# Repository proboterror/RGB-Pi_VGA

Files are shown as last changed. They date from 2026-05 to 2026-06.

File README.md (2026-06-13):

# RGB-Pi with VGA 15 kHz

Improved [RGB-Pi adapter](https://www.rgb-pi.com) for use with RGB-Pi OS.

Based on [open schematic published by mortaca](https://github.com/mortaca/RGB-Pi).

Original RGB-Pi documentation: [www.mortaca.com/docs/wiki](https://www.mortaca.com/docs/wiki/index.php?title=RGB-Pi)

Changes:
- Added VGA (DSUB-15) 15 kHz connector (Warning: 31 kHz VGA monitors not supported). 
- Proper sync combiner, borrowed from from [BKM-129X clone board](https://github.com/skumlos/bkm-129x-scart-vga), see also [KabukiFlux's RGBpi cable sync mixer](https://github.com/KabukiFlux/pi-rgb-cable-sync-mixer).
- Improved R-2R RGB DAC.
- PWM audio buffered with [SN74LVC2G34 Dual Buffer Gate](<datasheets/SN74LVC2G34 Dual Buffer Gate.pdf>) powered from [PS7A2033 Ultra-Low-Noise LDO](<datasheets/TPS7A20 300-mA, Ultra-Low-Noise, Low-IQ, High PSRR LDO.pdf>), with separate analog ground, in order to reduce Raspberry Pi internal power noise.
- Added 3.5 mm audio jack connector.

## Schematics:<br>
Scheme

## Board view:<br>
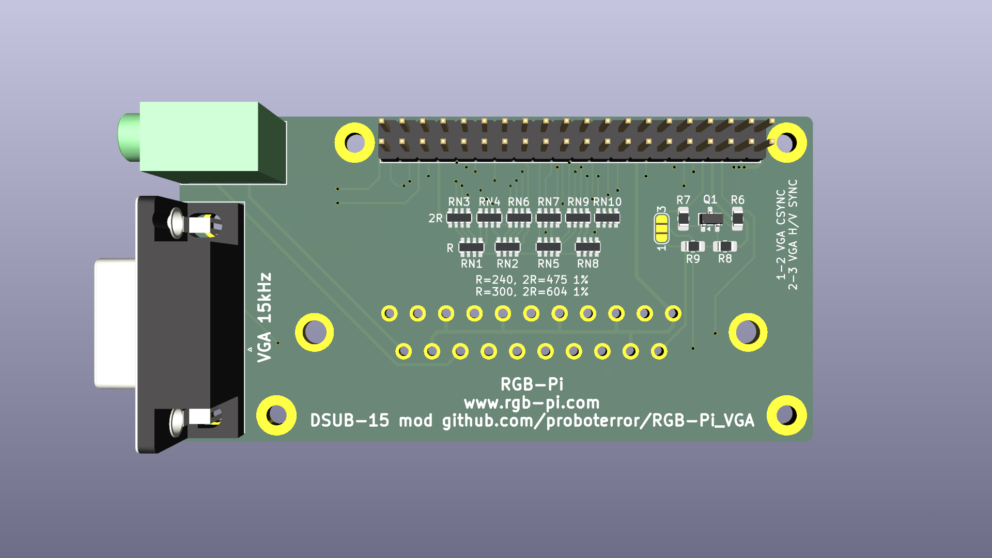
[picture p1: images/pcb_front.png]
Front

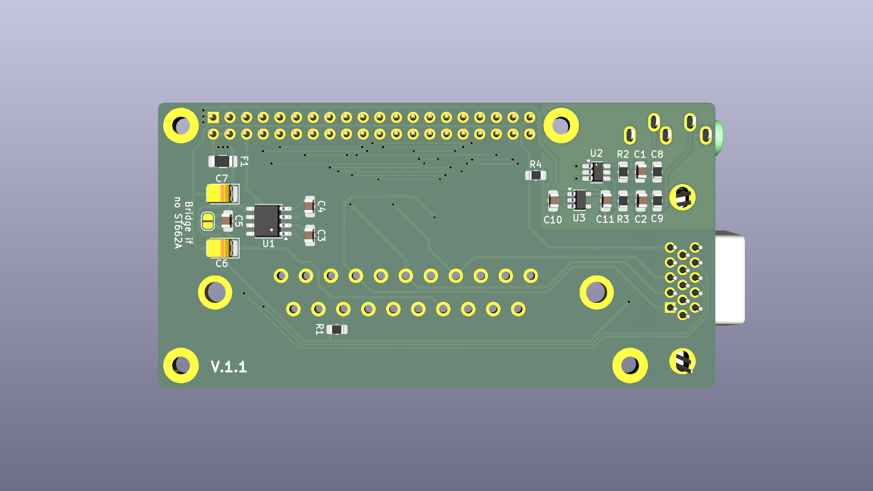
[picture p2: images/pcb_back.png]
Back

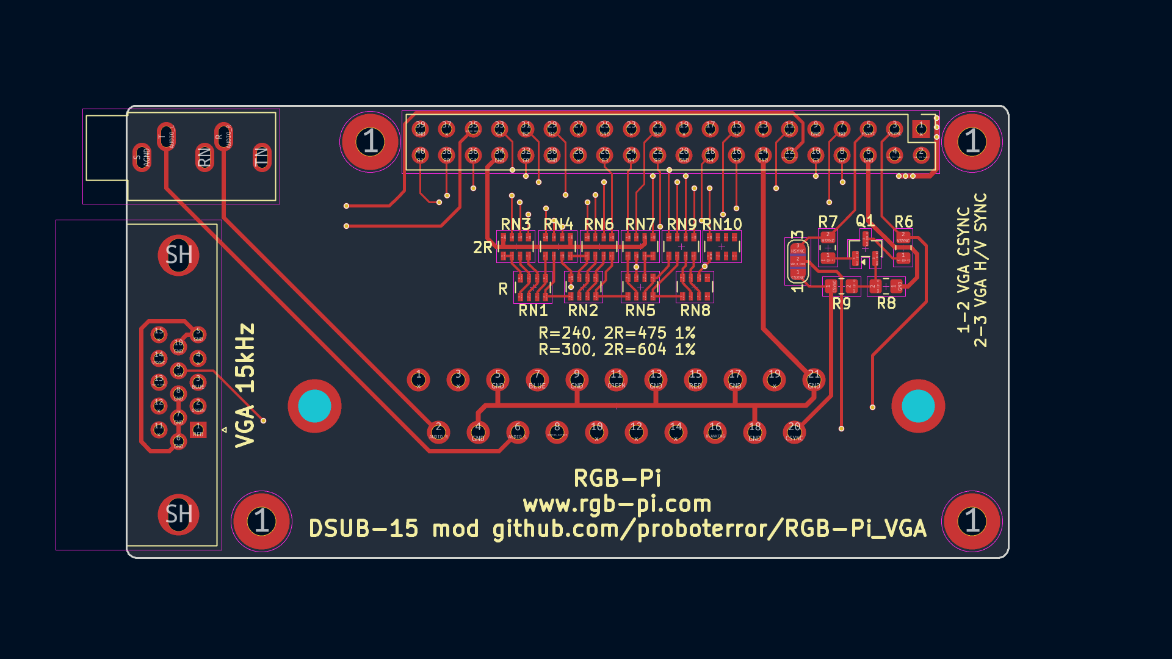
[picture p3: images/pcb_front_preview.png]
Front preview

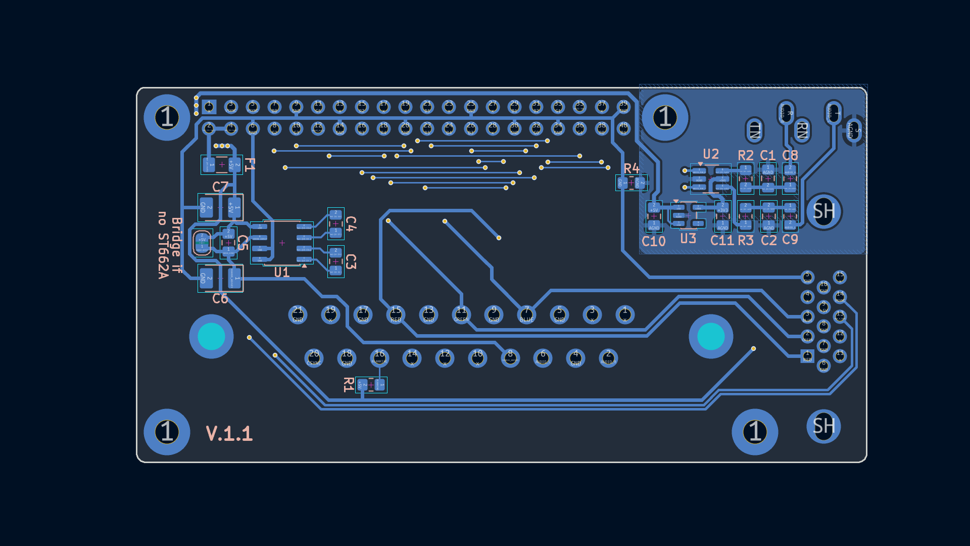
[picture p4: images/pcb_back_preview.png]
Back preview

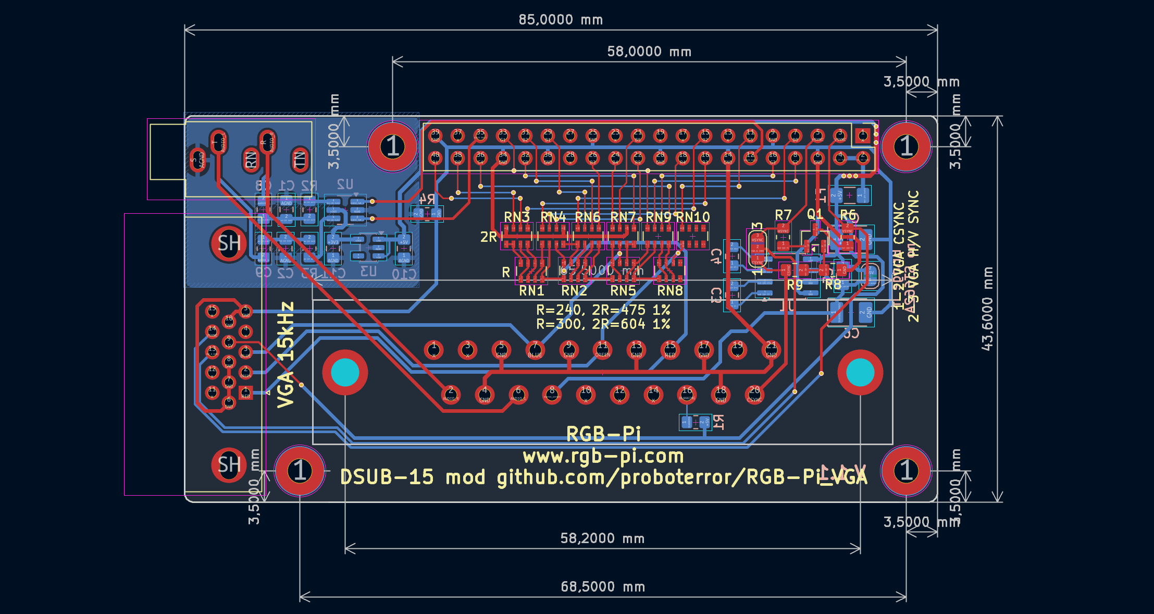
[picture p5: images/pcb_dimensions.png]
PCB dimensions


## Bill of Materials
|Reference|Value|Footprint|Qty|
|-----|-----|-----|-----|
|C1,C2|100nF|0805|2|
|C8,C9|10uF|0805|2|
|U2|SN74LVC2G34DBVR|SOT-23-6|1|
|U3|TPS7A2033PDBVR|SOT-23-5|1|
|F1|MF-NSMF012-2| 1206 Bourns MF-NSMF012-2 0.12A 30V|1|
|J1|Raspberry_Pi_4| PinHeader_2x20_P2.54mm_Vertical |1|
|J2|SCART-F|CS-102 (SCART-21S)|1|
|J3|DE15 Socket / DSUB-15-HD / VGA| DSUB-15-HD_Socket_Horizontal P2.29x1.90mm EdgePinOffset3.03mm MountingHolesOffset4.94mm|1|
|J4|SJ1-3535NG|CUI/Same Sky Device SJ1-3535NG|1|
|Q1|MMBT3904|SOT-23|1|
|R1|120R|0805|1|
|R2,R3|1K|0805|2|
|R6|100R|0805|1|
|R7|10K|0805|1|
|R8|1K|0805|1|
|R9|470R|0805|1|
|RN1,RN2,RN5,RN8|R = 240R or 300R 1%|Resistor Array 4x0603 |4|
|RN3,RN4,RN6,RN7,RN9,RN10|2R = 475R or 604R 1%|Resistor Array 4x0603|6|

Optional (SCART 5V->12V Converter for Status & Aspect Ratio switch):

|Reference|Value|Footprint|Qty|
|-----|-----|-----|-----|
|C5|100nF|0805|1|
|C3,C4|220nF|0805|2|
|C6,C7|4.7uF|Tantalum EIA-3528-21 / Kemet-B|2|
|U1|ST662A|SO-8_3.9x4.9mm_P1.27mm|1|

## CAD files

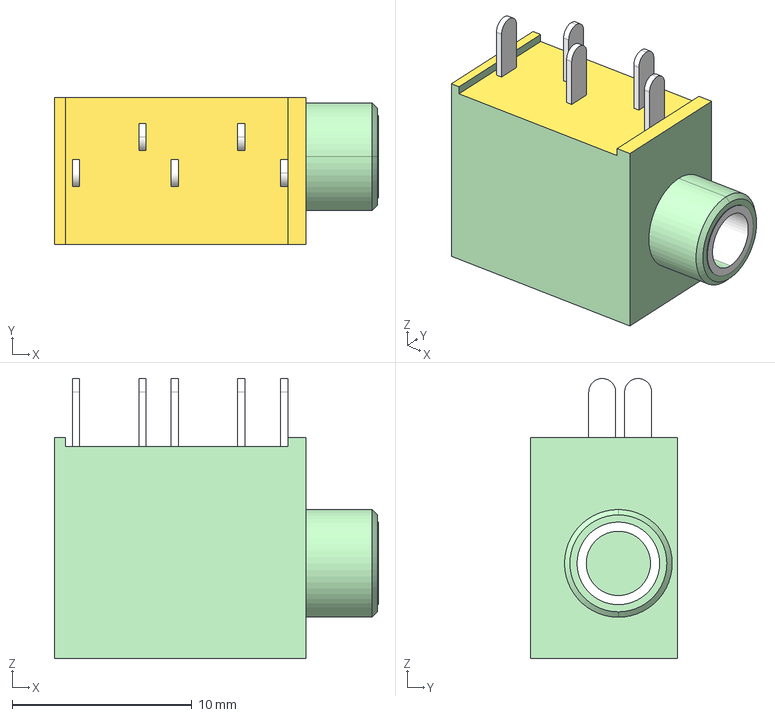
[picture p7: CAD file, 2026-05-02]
KiCad/3dshapes/CUI_DEVICES_SJ1-3535NG-G.step
18.1 x 8.20 x 15.6 mm

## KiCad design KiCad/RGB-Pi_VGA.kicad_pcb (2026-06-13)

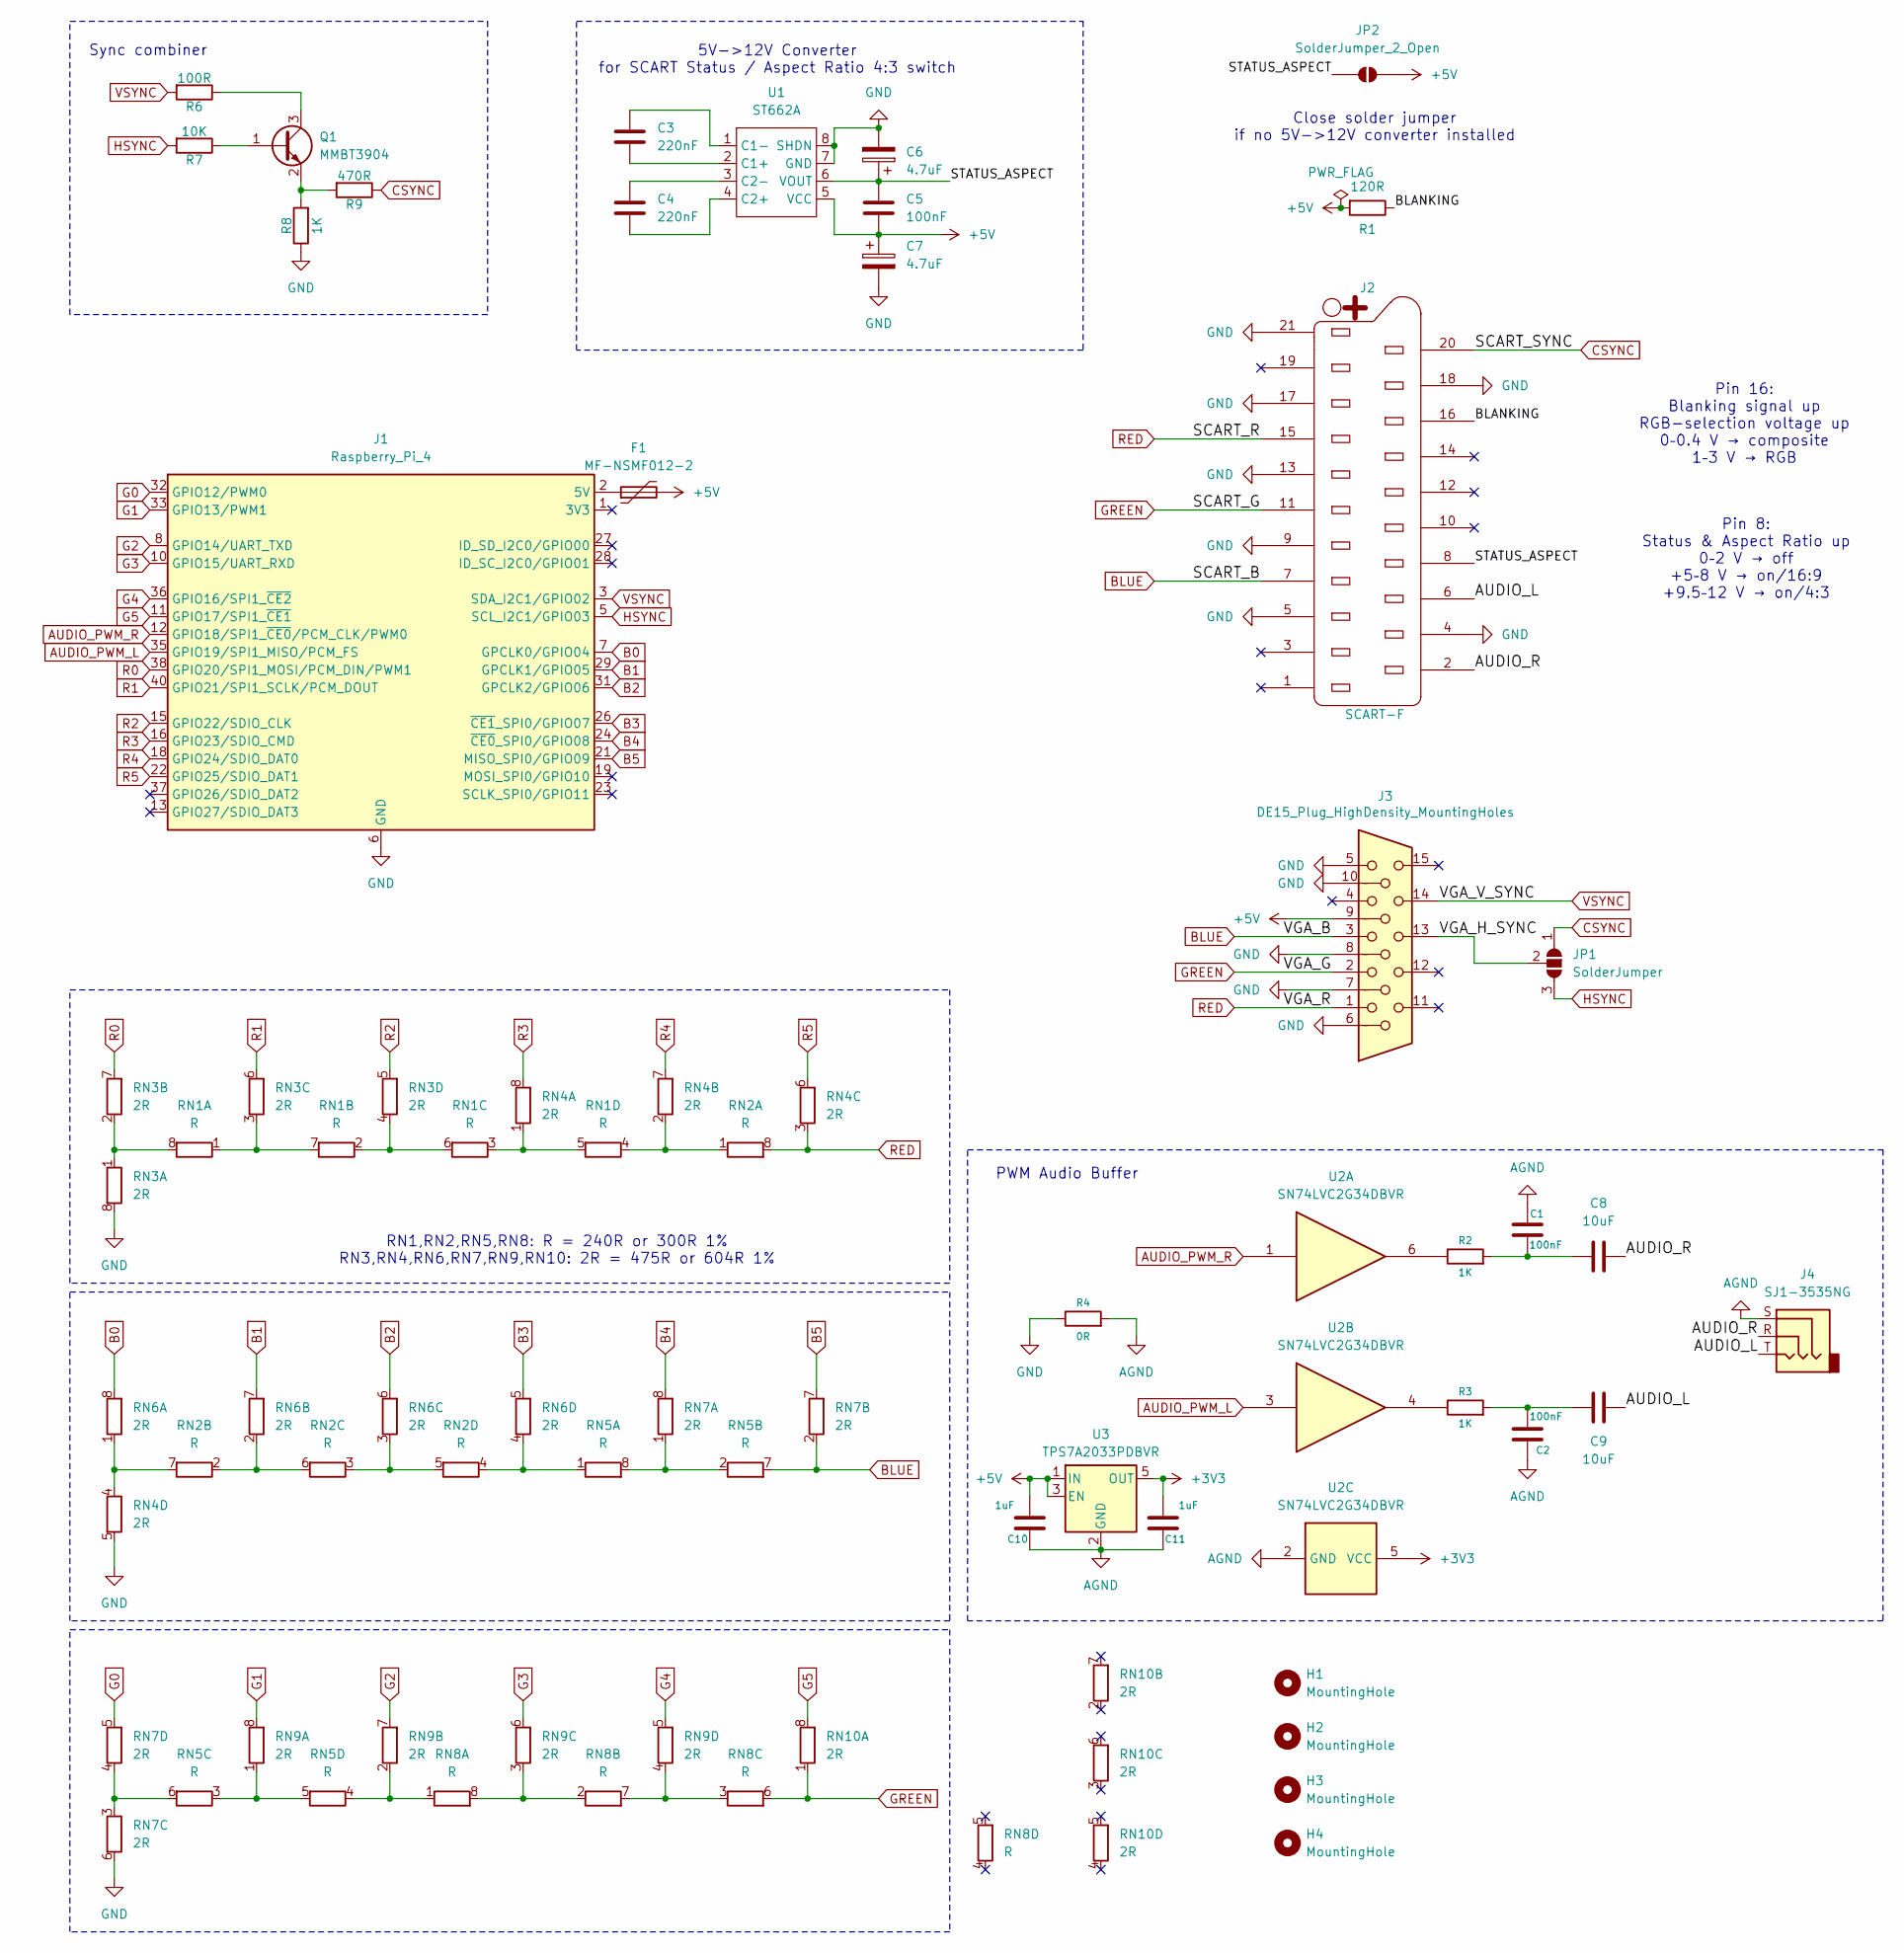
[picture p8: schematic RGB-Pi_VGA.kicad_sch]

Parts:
C1, C2, C5: 100nF; C_0805_2012Metric_Pad1.18x1.45mm_HandSolder
C3, C4: 220nF; C_0805_2012Metric_Pad1.18x1.45mm_HandSolder
C6, C7: 4.7uF; CP_EIA-3528-21_Kemet-B_HandSolder
C8, C9: 10uF; R_0805_2012Metric_Pad1.20x1.40mm_HandSolder
C10, C11: 1uF; C_0805_2012Metric_Pad1.18x1.45mm_HandSolder
F1: MF-NSMF012-2; Fuse_1206_3216Metric_Pad1.42x1.75mm_HandSolder
H1, H2, H3, H4: MountingHole; MountingHole_2.7mm_Pad
J1: Raspberry_Pi_4; PinHeader_2x20_P2.54mm_Vertical
J2: SCART-F; K-SCARTX-024
J3: DE15_Plug_HighDensity_MountingHoles; DSUB-15-HD_Socket_Horizontal_P2.29x1.90mm_EdgePinOffset3.03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
J4: SJ1-3535NG; Jack_3.5mm_CUI_SJ1-3535NG_Horizontal
JP1: SolderJumper; SolderJumper-3_P1.3mm_Open_RoundedPad1.0x1.5mm_NumberLabels
JP2: SolderJumper_2_Open; SolderJumper-2_P1.3mm_Open_RoundedPad1.0x1.5mm
Q1: MMBT3904; SOT-23
R1: 120R; R_0805_2012Metric_Pad1.20x1.40mm_HandSolder
R2, R3, R8: 1K; R_0805_2012Metric_Pad1.20x1.40mm_HandSolder
R4: 0R; R_0805_2012Metric_Pad1.20x1.40mm_HandSolder
R6: 100R; R_0805_2012Metric_Pad1.20x1.40mm_HandSolder
R7: 10K; R_0805_2012Metric_Pad1.20x1.40mm_HandSolder
R9: 470R; R_0805_2012Metric_Pad1.20x1.40mm_HandSolder
RN1, RN2, RN5, RN8: R; R_Array_Convex_4x0603
RN3, RN4, RN6, RN7, RN9, RN10: 2R; R_Array_Convex_4x0603
U1: ST662A; SO-8_3.9x4.9mm_P1.27mm
U2: SN74LVC2G34DBVR; SOT-23-6_Handsoldering
U3: TPS7A2033PDBVR; SOT-23-5

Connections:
+3V3: C11.2, U2.5 (VCC), U3.5 (OUT)
+5V: C5.2, C7.1, C10.2, F1.2, J3.9, JP2.2 (B), R1.2, U1.5 (VCC), U3.1 (IN), U3.3 (EN)
/AUDIO_L: C9.2, J2.6, J4.T
/AUDIO_R: C8.2, J2.2, J4.R
/BLANKING: J2.16, R1.1
/STATUS_ASPECT: C5.1, C6.1, J2.8, JP2.1 (A), U1.6 (VOUT)
/VGA_H_SYNC: J3.13, JP1.2 (C)
AGND: C1.1, C2.1, C10.1, C11.1, J4.S, R4.2, U2.2 (GND), U3.2 (GND)
AUDIO_PWM_L: J1.35 (GPIO19/SPI1_MISO/PCM_FS), U2.3
AUDIO_PWM_R: J1.12 (GPIO18/SPI1_~CE0/PCM_CLK/PWM0), U2.1
B0: J1.7 (GPCLK0/GPIO04), RN6.8 (R1.2)
B1: J1.29 (GPCLK1/GPIO05), RN6.7 (R2.2)
B2: J1.31 (GPCLK2/GPIO06), RN6.6 (R3.2)
B3: J1.26 (~CE1_SPI0/GPIO07), RN6.5 (R4.2)
B4: J1.24 (~CE0_SPI0/GPIO08), RN7.8 (R1.2)
B5: J1.21 (MISO_SPI0/GPIO09), RN7.7 (R2.2)
BLUE: J2.7, J3.3, RN5.7 (R2.2), RN7.2 (R2.1)
CSYNC: J2.20, JP1.1 (A), R9.1
G0: J1.32 (GPIO12/PWM0), RN7.5 (R4.2)
G1: J1.33 (GPIO13/PWM1), RN9.8 (R1.2)
G2: J1.8 (GPIO14/UART_TXD), RN9.7 (R2.2)
G3: J1.10 (GPIO15/UART_RXD), RN9.6 (R3.2)
G4: J1.36 (GPIO16/SPI1_~CE2), RN9.5 (R4.2)
G5: J1.11 (GPIO17/SPI1_~CE1), RN10.8 (R1.2)
GND: C6.2, C7.2, J1.6 (GND), J1.9 (GND), J1.14 (GND), J1.20 (GND), J1.25 (GND), J1.30 (GND), J1.34 (GND), J1.39 (GND), J2.4, J2.5, J2.9, J2.13, J2.17, J2.18, J2.21, J3.5, J3.6, J3.7, J3.8, J3.10, R4.1, R8.1, RN3.8 (R1.2), RN4.5 (R4.2), RN7.6 (R3.2), U1.7 (GND), U1.8 (SHDN)
GREEN: J2.11, J3.2, RN8.6 (R3.2), RN10.1 (R1.1)
HSYNC: J1.5 (SCL_I2C1/GPIO03), JP1.3 (B), R7.2
unnamed: C1.2, C8.1, R2.2
unnamed: C2.2, C9.1, R3.2
unnamed: F1.1, J1.2 (5V), J1.4 (5V)
unnamed: Q1.1 (B), R7.1
unnamed: Q1.3 (C), R6.1
unnamed: Q1.2 (E), R8.2, R9.2
unnamed: R2.1, U2.6
unnamed: R3.1, U2.4
unnamed: RN1.1 (R1.1), RN1.7 (R2.2), RN3.3 (R3.1)
unnamed: RN1.8 (R1.2), RN3.1 (R1.1), RN3.2 (R2.1)
unnamed: RN1.2 (R2.1), RN1.6 (R3.2), RN3.4 (R4.1)
unnamed: RN1.3 (R3.1), RN1.5 (R4.2), RN4.1 (R1.1)
unnamed: RN1.4 (R4.1), RN2.1 (R1.1), RN4.2 (R2.1)
unnamed: RN2.2 (R2.1), RN2.6 (R3.2), RN6.2 (R2.1)
unnamed: RN2.7 (R2.2), RN4.4 (R4.1), RN6.1 (R1.1)
unnamed: RN2.3 (R3.1), RN2.5 (R4.2), RN6.3 (R3.1)
unnamed: RN2.4 (R4.1), RN5.1 (R1.1), RN6.4 (R4.1)
unnamed: RN5.2 (R2.1), RN5.8 (R1.2), RN7.1 (R1.1)
unnamed: RN5.3 (R3.1), RN5.5 (R4.2), RN9.1 (R1.1)
unnamed: RN5.6 (R3.2), RN7.3 (R3.1), RN7.4 (R4.1)
unnamed: RN5.4 (R4.1), RN8.1 (R1.1), RN9.2 (R2.1)
unnamed: RN8.2 (R2.1), RN8.8 (R1.2), RN9.3 (R3.1)
unnamed: RN8.3 (R3.1), RN8.7 (R2.2), RN9.4 (R4.1)
unnamed: C3.2, U1.2 (C1+)
unnamed: C3.1, U1.1 (C1-)
unnamed: C4.2, U1.4 (C2+)
unnamed: C4.1, U1.3 (C2-)
R0: J1.38 (GPIO20/SPI1_MOSI/PCM_DIN/PWM1), RN3.7 (R2.2)
R1: J1.40 (GPIO21/SPI1_SCLK/PCM_DOUT), RN3.6 (R3.2)
R2: J1.15 (GPIO22/SDIO_CLK), RN3.5 (R4.2)
R3: J1.16 (GPIO23/SDIO_CMD), RN4.8 (R1.2)
R4: J1.18 (GPIO24/SDIO_DAT0), RN4.7 (R2.2)
R5: J1.22 (GPIO25/SDIO_DAT1), RN4.6 (R3.2)
RED: J2.15, J3.1, RN2.8 (R1.2), RN4.3 (R3.1)
VSYNC: J1.3 (SDA_I2C1/GPIO02), J3.14, R6.2

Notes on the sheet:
5V->12V Converter for SCART Status / Aspect Ratio 4:3 switch
PWM Audio Buffer
RN1,RN2,RN5,RN8: R = 240R or 300R 1% RN3,RN4,RN6,RN7,RN9,RN10: 2R = 475R or 604R 1%
Pin 16: Blanking signal up RGB-selection voltage up 0–0.4 V → composite 1–3 V → RGB
Sync combiner
Close solder jumper if no 5V->12V converter installed
Pin 8: Status & Aspect Ratio up 0–2 V → off +5–8 V → on/16:9 +9.5–12 V → on/4:3

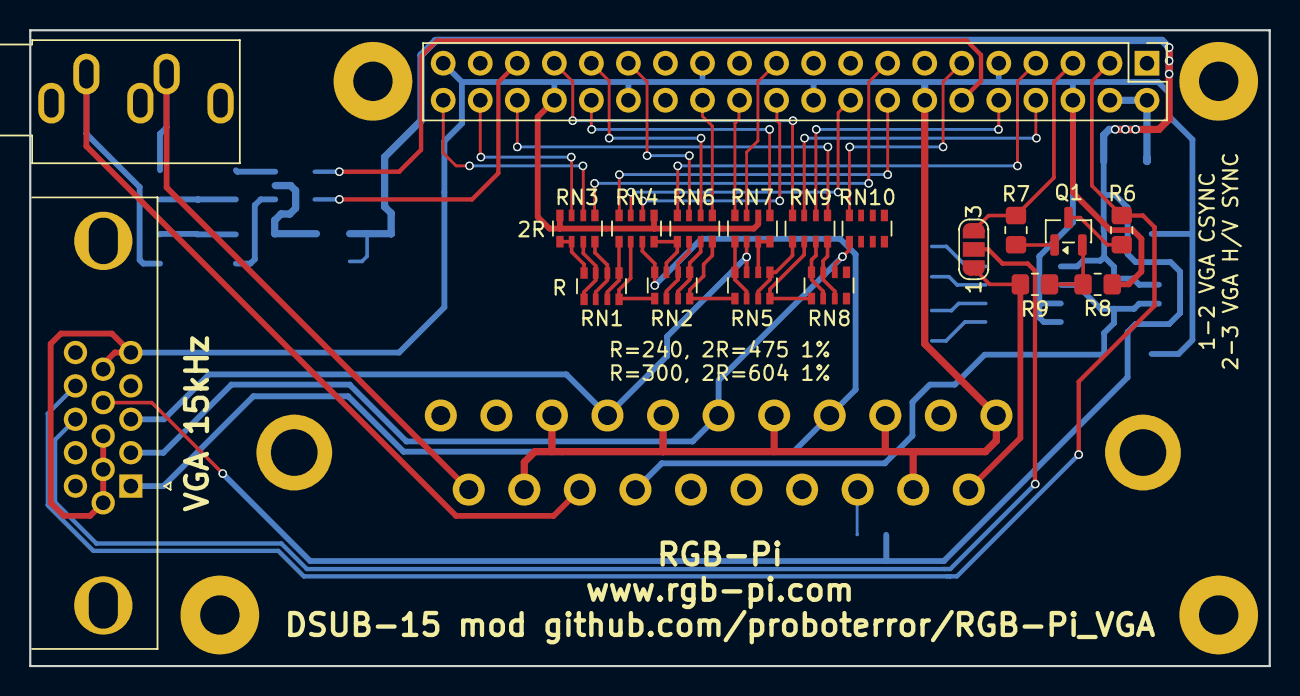
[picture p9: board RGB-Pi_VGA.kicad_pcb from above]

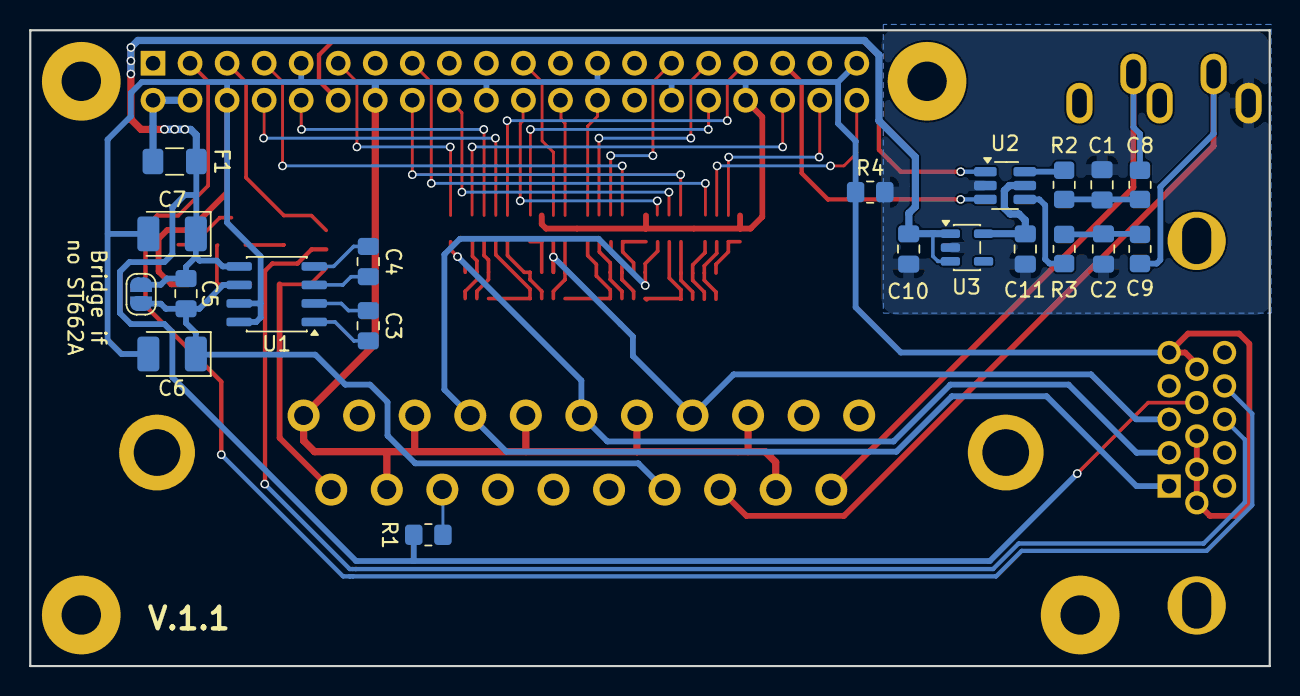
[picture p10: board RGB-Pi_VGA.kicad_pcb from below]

Board: 2 copper layers, 85.0 x 43.6 mm, 44 parts (20 on the bottom side), 62 nets.

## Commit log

2026-05-02 Initial implementation.
    [CUI_DEVICES_SJ1-3535NG-G.step, RGB-Pi_VGA.kicad_pcb, RGB-Pi_VGA.kicad_sch]
2026-05-02 Add +5V PWR_FLAG to schematic.
    [RGB-Pi_VGA.kicad_sch]
2026-05-02 Add PCB dimension.
    [RGB-Pi_VGA.kicad_pcb]
2026-05-02 Change C8, C9 footprints from 1206 to 0805.
    [RGB-Pi_VGA.kicad_pcb, RGB-Pi_VGA.kicad_sch]
2026-05-02 Update svg schematic dimensions.
2026-05-27 Correct DE15/VGA connector pinout.
    [RGB-Pi_VGA.kicad_sch]
2026-05-27 Update PCB matching schematic.
    [RGB-Pi_VGA.kicad_pcb]
2026-06-13 Board version 1.1. Correct VGA connector pinout. PWM audio buffered with SN74LVC2G34 Dual Buffer Gate, powered from PS7A2033 Ultra-Low-Noise LDO, with separate analog ground, in order to reduce Raspb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
    [RGB-Pi_VGA.kicad_pcb, RGB-Pi_VGA.kicad_sch]
